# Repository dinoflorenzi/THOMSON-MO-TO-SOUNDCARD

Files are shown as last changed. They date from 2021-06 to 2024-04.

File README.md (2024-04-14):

# PC128 OLIVETTI PRODEST - THOMSON MO/TO SOUNDCARD

# Attention, YM2413 sound card project is still in the prototype state.
# Only the previous versions made have been tested only on PC 128 OLIVETTI PRODEST.
# The last versions with minimal changes and corrections are under test.
# Otherwise, there is an all-in-one version, developed and built by Sebastien that fully works (https://github.com/Sebastus1976/Amadeus).

## PROJECT OVERVIEW
This is a project is born to build a secondary sound card expansion for my PC 128 OLIVETTI PRODEST HOME COMPUTER.<br/>
I have designed and built two different sound cards based on two different sound chip.<br/>
One sound card is based on PSG SN76489AN sound chip, the second is based on OPLL YM2413 sound chip.<br/>
Also i have coded the ASM 6809 routines to play sound demos.<br/>

## HOW IT STARTED
Thomson computers have sound generator simply based on 6bit dac that fully commits the cpu countinuosly updating the sound samples. During sound streaming the computer can't do anything else.<br/>
Beucause of that there was the need to develop a secondary sound card based on specific sound chip that generates sound by itself, only programming your own registers.<br/>
## START POINT
Thomson computers have an expansion port with the main computer signals, data bus, address bus, chip select, master clock, and analog sound input that is mixed with the main sound generator.<br/>
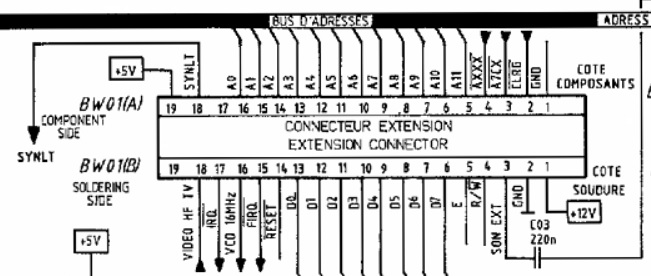
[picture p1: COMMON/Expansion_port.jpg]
<br/>
## SOUND CHIP SELECTION CRITERION
The SN76489AN first chip selection is based on its simple architecture, 8 bit bus, four channels, up to two write sequences to generates sound or noise.<br/>
The YM2413 second chip selection is also based on its simple architecture, 8 bit bus, nine channels, two write addresses to generates sound with hardware instruments and rythems.<br/>
Single board develepments are better described to the links below or wiki section<br/>
[SN76489AN SOUND CARD DEVELOPMENT](https://github.com/dinoflorenzi/THOMSON-MO-TO-SOUNDCARD/wiki/SN76489AN-MOTO-SOUND-CARD)<br/>
[YM2413 SOUND CARD DEVELOPMENT](https://github.com/dinoflorenzi/THOMSON-MO-TO-SOUNDCARD/wiki/YM2413-MOTO-SOUND-CARD)<br/>
## CONTEMPORARY USAGE
By properly setting card jumpers it changes the address. In this way you can mount two sound cards working  simultaneously.<br/>
The interconnection card is a third-party project.<br/>
The assembly of the cards in this photo is the precious contribution of Benoit Rousseau. He help me to debug the cards on Thomson TO target.<br/>
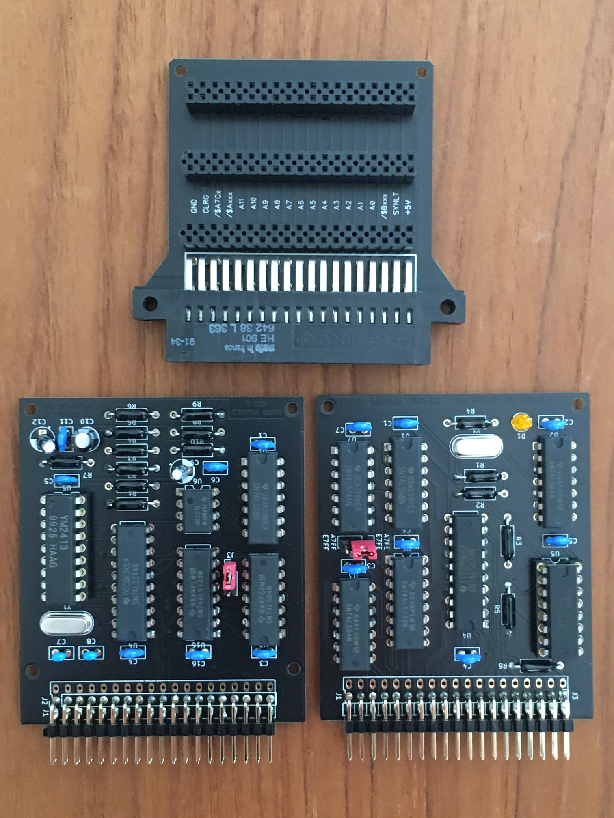
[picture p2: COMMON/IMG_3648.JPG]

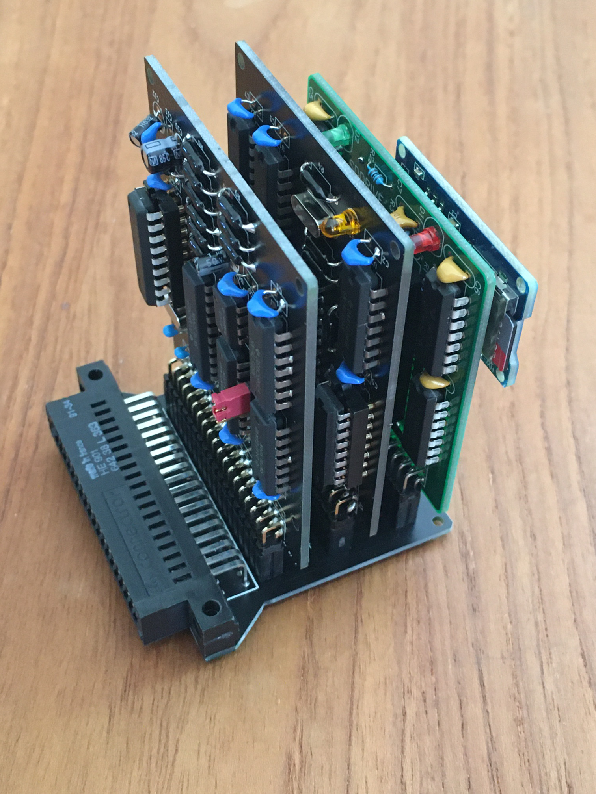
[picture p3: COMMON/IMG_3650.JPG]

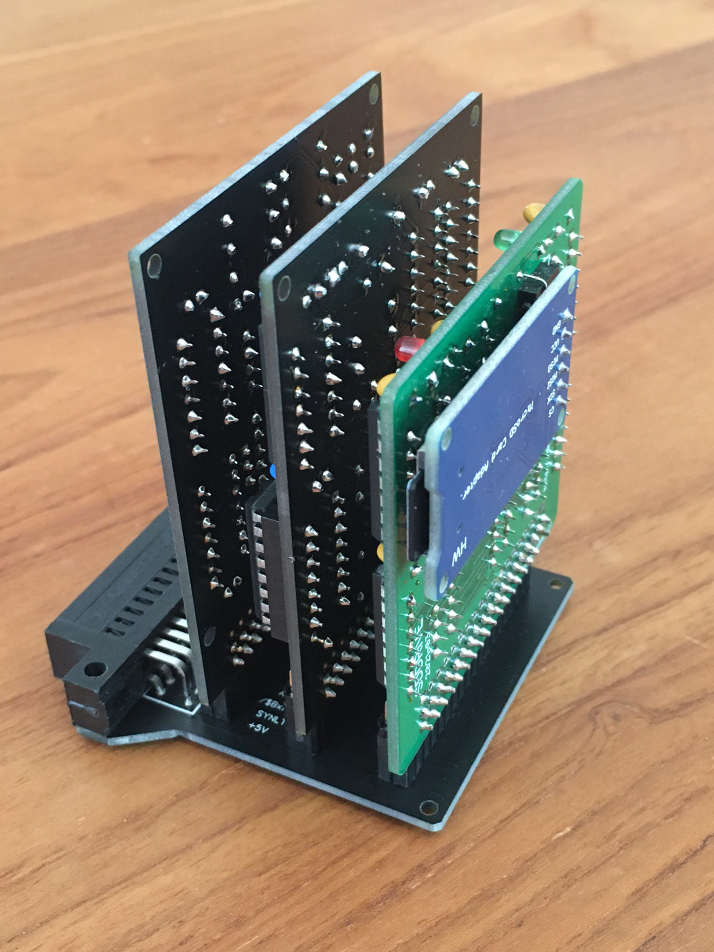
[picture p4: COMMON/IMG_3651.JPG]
<br/>
## SOFTWARE TOOLS
[Kicad](https://www.kicad.org/) and [Freerounting](https://freerouting.org/) to develop schematics and pcb.<br/>
DCMOTO emulator fully emulates both sound cards (http://dcmoto.free.fr/emulateur/index.html)<br/>
## RESOURCES
https://en.wikipedia.org/wiki/Texas_Instruments_SN76489<br/>
https://en.wikipedia.org/wiki/Yamaha_YM2413<br/>
http://dcmoto.free.fr/<br/>
https://vgmrips.net/packs/<br/>
https://www.smspower.org/Music/VGMs<br/>
http://atjs.mbnet.fi/mc6809/<br/>
http://map.grauw.nl/resources/sound/texas_instruments_sn76489an.pdf<br/>
http://map.grauw.nl/resources/sound/yamaha_ym2413_ds.pdf<br/>

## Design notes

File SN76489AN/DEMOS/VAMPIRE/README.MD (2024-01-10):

This folder contains the DCMOTO snapshot of a modified version of the Vampire game for PC 128 Olivetti Prodest(Thomson Mo6). This version uses the SN76489 soundcard or Amadeus soundcard to play a background music.
The files inject.asm and vampire_music.asm contain a detailed description of the assembly code and the steps to modify the original game code. 
https://youtu.be/lTLiAmxgv30

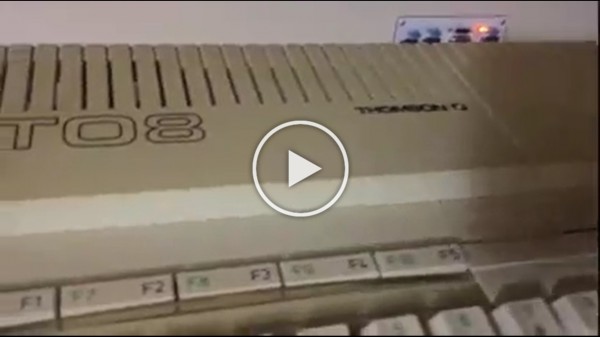
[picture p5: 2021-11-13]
SN76489AN/61901a118f727-fbutube-adnz.jpeg

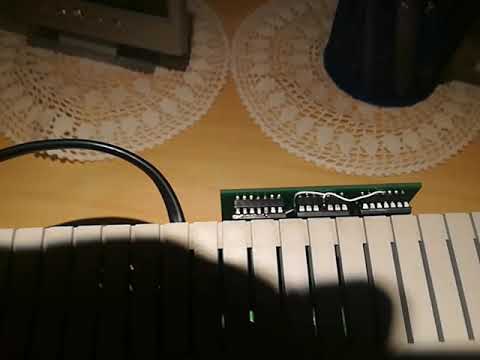
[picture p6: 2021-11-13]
SN76489AN/68747470733a2f2f696d672e796f75747562652e636f6d2f76692f6a7777616a724e703954732f302e6a7067.jpg

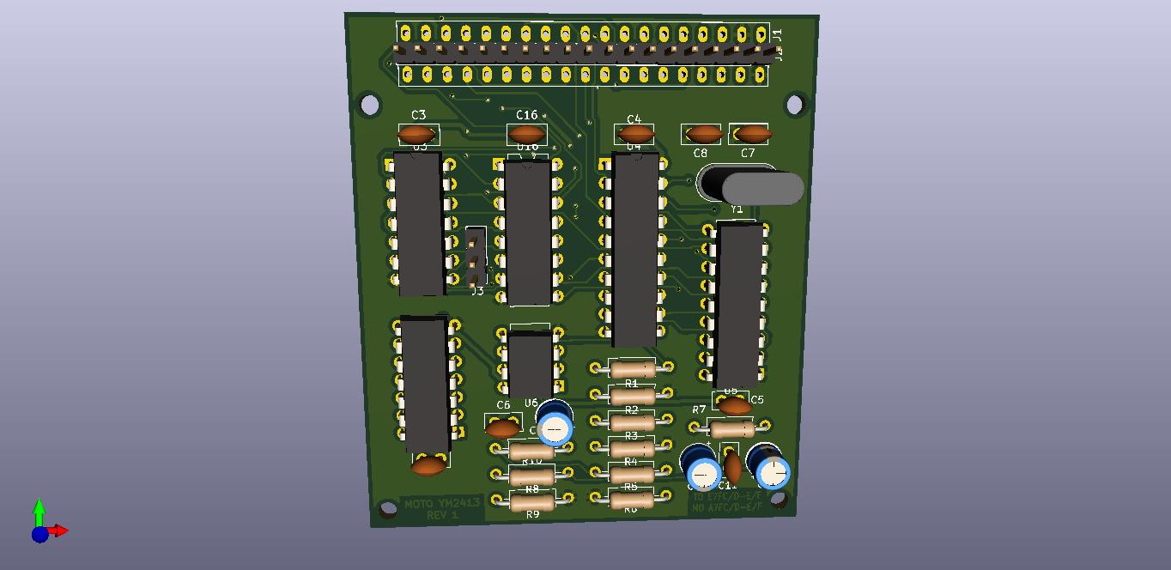
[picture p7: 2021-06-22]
YM2413/YM2413_MOTO_3D.jpg

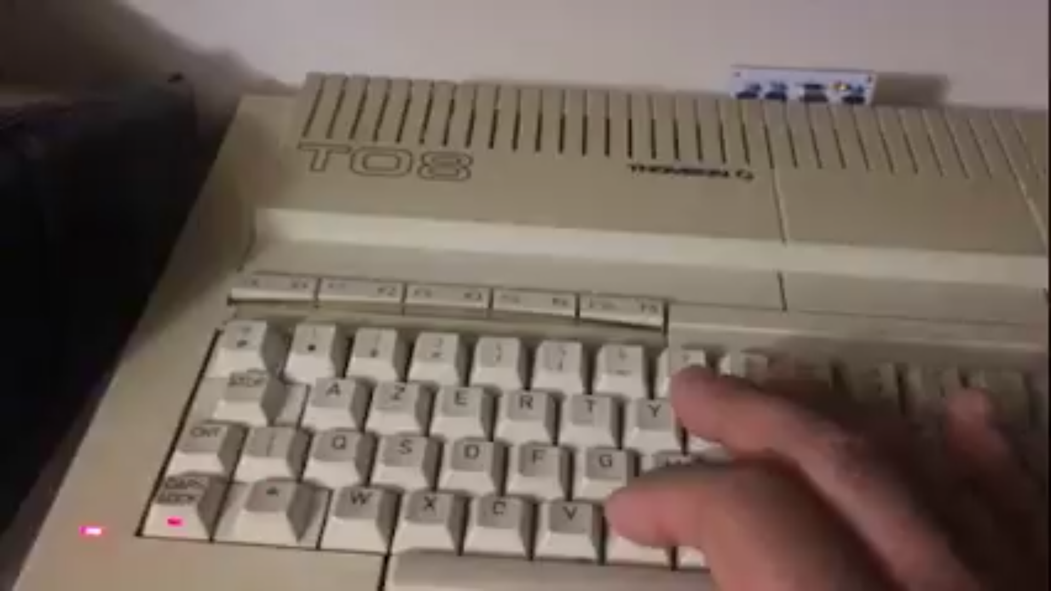
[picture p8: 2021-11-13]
SN76489AN/Screenshot_20211113-132706.png

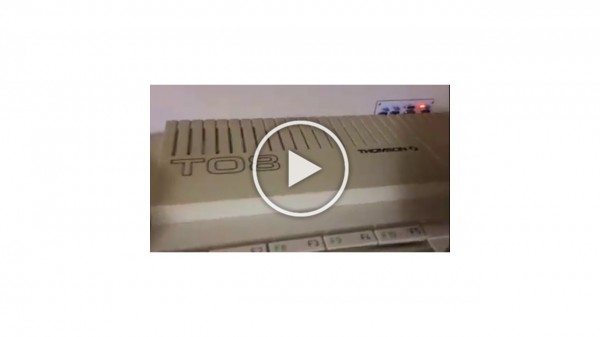
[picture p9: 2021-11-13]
SN76489AN/adnz.jpeg

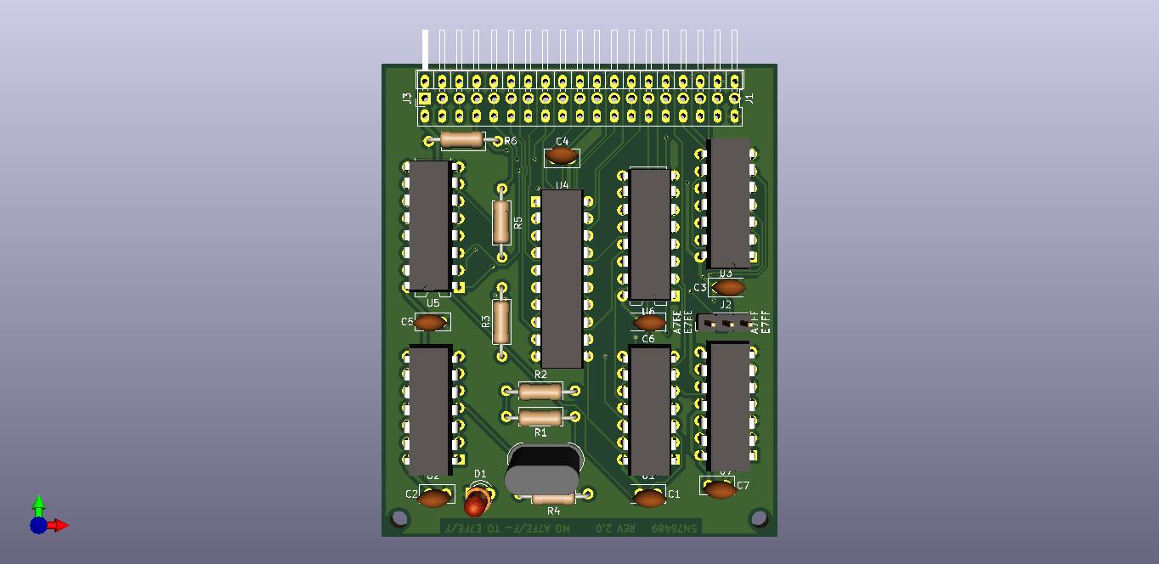
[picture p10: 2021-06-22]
SN76489AN/SN76489_MOTO_3D.jpg

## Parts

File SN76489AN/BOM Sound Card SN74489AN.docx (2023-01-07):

BOM SN76489AN

IC:

-1X 74LS08

-1X 74LS373

-1x 74LS133

-2X 74LS04

-1X SN76489AN

CAPACITORS :

-7X 100nf ceramic

RESISTORS :

-3x 2 kohms metal metal

-1x 250 ohms metal film

-2x 1 kohms film métal

OTHER :

-1X Led 3.5 mm

-1X Quartz 3.579545 Mhz

-1X PCB

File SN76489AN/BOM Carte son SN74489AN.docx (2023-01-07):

BOM SN76489AN

CI:

-1X 74LS08

-1X 74LS373

-1x 74LS133

-2X 74LS04

-1X SN76489AN

CONDENSATEUR :

-7X 100nf céramique multicouches

RESISTANCES :

-3x 2 kohms film métal

-1x 250 ohms film métal

-2x 1 kohms film métal

AUTRES :

-1X Led 3.5 mm

-1X Quartz 3.579545 Mhz

-1X Circuit imprimé

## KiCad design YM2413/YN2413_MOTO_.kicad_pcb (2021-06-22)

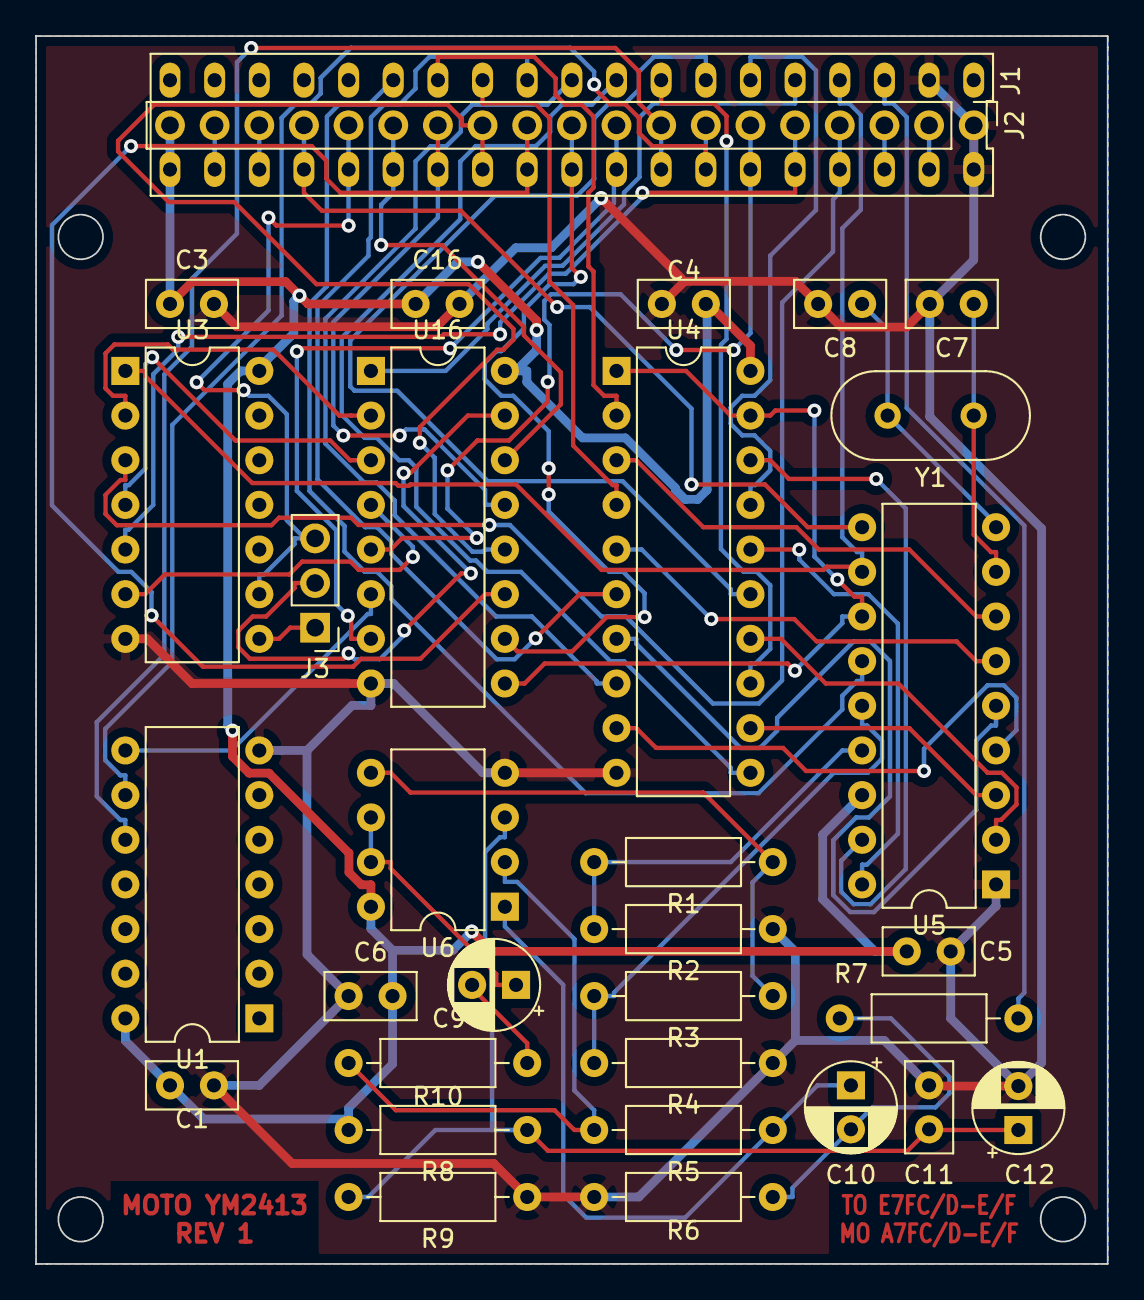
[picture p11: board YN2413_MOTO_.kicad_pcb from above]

Board: 2 copper layers, 61.0 x 69.8 mm, 32 parts (0 on the bottom side), 57 nets.

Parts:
C1, C3, C4, C5, C6, C11, C16: 100nF; C_Disc_D5.0mm_W2.5mm_P2.50mm
C7, C8: 27pF; C_Disc_D5.0mm_W2.5mm_P2.50mm
C9, C12: 1uF; CP_Radial_D5.0mm_P2.50mm
C10: 10uF; CP_Radial_D5.0mm_P2.50mm
J1: Conn_02x19_Row_Letter_Last; DIP-38_Edge_Connector
J2: Conn_01x19; PinHeader_1x19_P2.54mm_Vertical
J3: Conn_01x03_Male; PinHeader_1x03_P2.54mm_Vertical
R1, R3: 4700; R_Axial_DIN0207_L6.3mm_D2.5mm_P10.16mm_Horizontal
R2, R4: 2200; R_Axial_DIN0207_L6.3mm_D2.5mm_P10.16mm_Horizontal
R5: 100K; R_Axial_DIN0207_L6.3mm_D2.5mm_P10.16mm_Horizontal
R6, R7, R8, R9: 1000; R_Axial_DIN0207_L6.3mm_D2.5mm_P10.16mm_Horizontal
R10: 10K; R_Axial_DIN0207_L6.3mm_D2.5mm_P10.16mm_Horizontal
U1: 74LS08; DIP-14_W7.62mm
U3: 74LS04; DIP-14_W7.62mm
U4: 74LS244; DIP-20_W7.62mm
U5: YM2413; DIP-18_W7.62mm
U6: TL072; DIP-8_W7.62mm
U16: 74LS133; DIP-16_W7.62mm
Y1: 3.576 MHz; Crystal_HC18-U_Vertical

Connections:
+5V: C1.1, C3.1, C4.1, C5.1, C6.2, C16.1, J1.19a, J2.19, R8.2, U1.14, U3.14, U4.20, U5.16, U6.8, U16.16
/A1: J1.15a, J2.15, J3.3, U3.9
/A2: J1.14a, J2.14, U16.14
/A3: J1.13a, J2.13, U16.13
/A4: J1.12a, J2.12, U16.12
/A5: J1.11a, J2.11, U16.11
/A6: J1.10a, J2.10, U16.10
/A7: J1.9a, J2.9, U16.7
/A8: J1.8a, J2.8, U1.10
/A9: J1.7a, J2.7, U1.9
/A10: J1.6a, J2.6, U16.5
/A11: J1.5a, J2.5, U3.5
/D0: J1.13b, U4.2
/D1: J1.12b, U4.4
/D2: J1.11b, U4.6
/D3: J1.10b, U4.8
/D4: J1.9b, U4.11
/D5: J1.8b, U4.13
/D6: J1.7b, U4.15
/D7: J1.6b, U4.17
/E: J1.5b, U16.1
/SON: J1.3b, R7.2
/\A7XX: J1.3a, J2.3
/\AXXX: J1.4a, J2.4, U3.3
/\CLRG: J1.2a, J2.2
A0: J1.16a, J2.16, U5.10
GND: C1.2, C3.2, C4.2, C5.2, C6.1, C7.2, C8.2, C11.1, C12.2, C16.2, J1.1a, J1.2b, J2.1, R2.1, R4.1, R6.1, R9.1, U1.7, U3.7, U4.10, U5.1, U6.4, U16.8
unnamed: C7.1, U5.8, Y1.1
unnamed: C8.1, U5.9, Y1.2
unnamed: C9.1, U6.6, U6.7
unnamed: C9.2, R10.2
unnamed: C10.1, R5.1, U6.1
unnamed: C10.2, R6.2, R7.1
unnamed: C11.2, C12.1, R8.1, R9.2, U6.3
unnamed: J1.17a, J2.17
unnamed: J1.18a, J2.18
unnamed: J3.1, U3.8
unnamed: J3.2, U16.15
unnamed: R1.1, R3.1, U6.5
unnamed: R1.2, R2.2, U5.15
unnamed: R3.2, R4.2, U5.14
unnamed: R5.2, R10.1, U6.2
unnamed: U1.8, U16.6
unnamed: U4.3, U5.7
unnamed: U4.5, U5.6
unnamed: U4.7, U5.5
unnamed: U4.9, U5.4
unnamed: U4.12, U5.3
unnamed: U4.14, U5.2
unnamed: U4.16, U5.18
unnamed: U4.18, U5.17
unnamed: U3.2, U16.2
unnamed: U3.4, U16.3
unnamed: U3.6, U16.4
unnamed: U4.1, U4.19, U5.12, U16.9
RESET: J1.14b, U5.13
RW: J1.4b, U3.1, U5.11

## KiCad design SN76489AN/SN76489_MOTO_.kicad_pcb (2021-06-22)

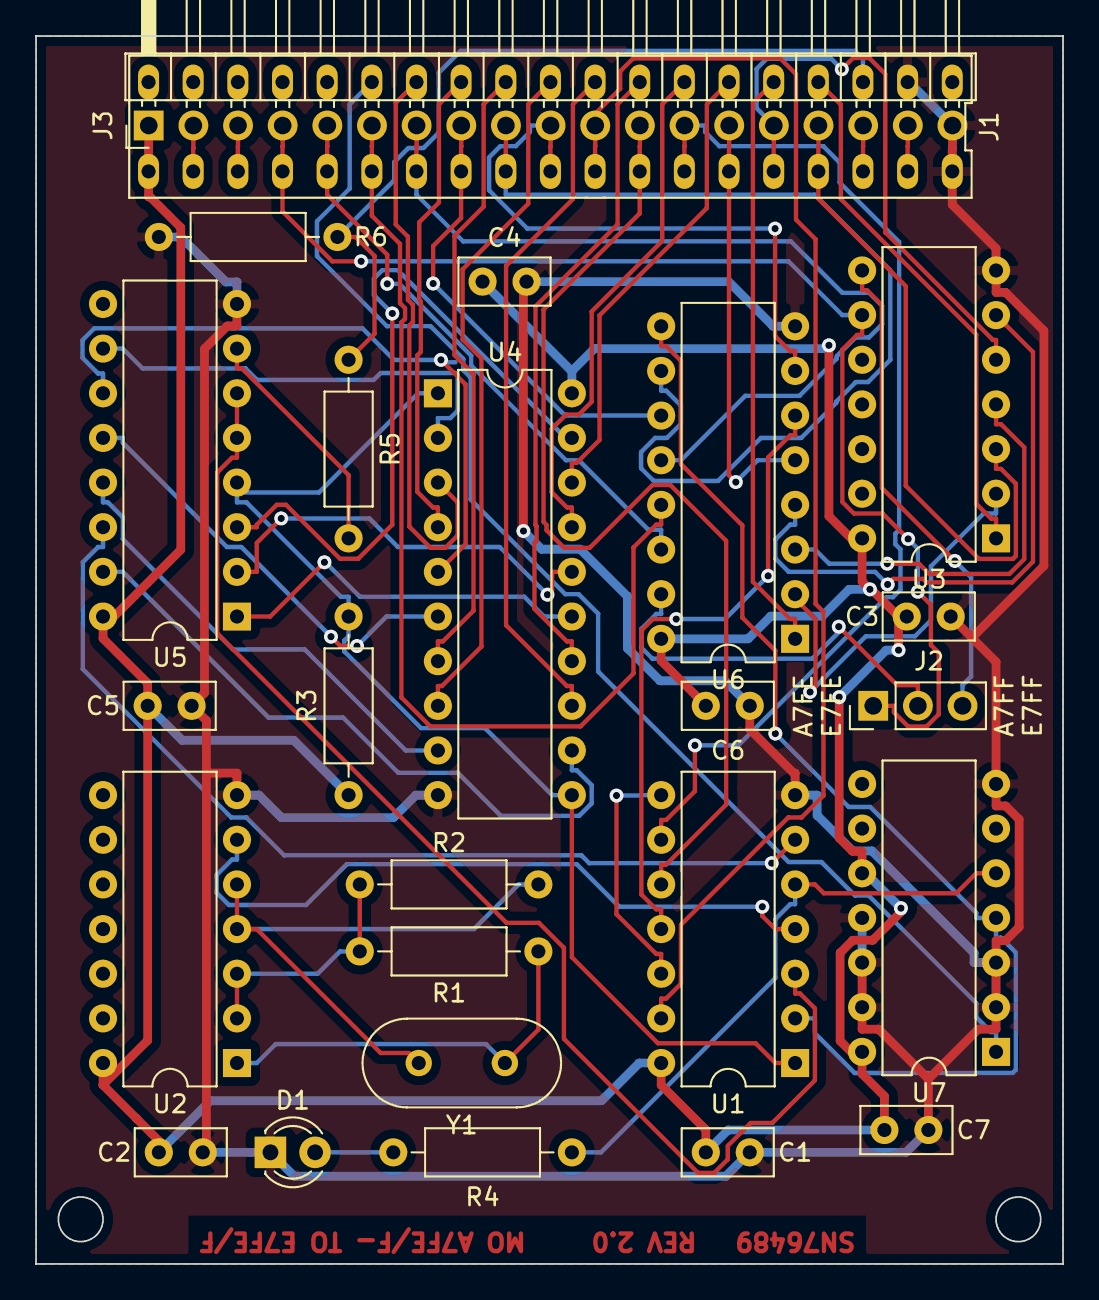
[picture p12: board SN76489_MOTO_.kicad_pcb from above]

Board: 2 copper layers, 58.4 x 69.8 mm, 25 parts (0 on the bottom side), 57 nets.

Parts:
C1, C2, C3, C4, C5, C6, C7: 100nF; C_Disc_D5.0mm_W2.5mm_P2.50mm
D1: LED; LED_D3.0mm
J1: Conn_02x19_Row_Letter_Last; DIP-38_Edge_Connector
J2: Conn_01x03_Male; PinHeader_1x03_P2.54mm_Vertical
J3: Conn_01x19; PinHeader_1x19_P2.54mm_Horizontal
R1, R2, R3: 2000; R_Axial_DIN0207_L6.3mm_D2.5mm_P10.16mm_Horizontal
R4: 250; R_Axial_DIN0207_L6.3mm_D2.5mm_P10.16mm_Horizontal
R5, R6: 1000; R_Axial_DIN0207_L6.3mm_D2.5mm_P10.16mm_Horizontal
U1: 74LS08; DIP-14_W7.62mm
U2, U3: 74LS04; DIP-14_W7.62mm
U4: 74LS373; DIP-20_W7.62mm
U5: SN76489AN; DIP-16_W7.62mm
U6: 74LS133; DIP-16_W7.62mm
U7: 74LS74; DIP-14_W7.62mm
Y1: 3.576 MHz; Crystal_HC18-U_Vertical

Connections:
+5V: C1.1, C2.1, C3.1, C4.1, C5.1, C6.1, C7.1, J1.19a, J3.1, R3.1, U1.14, U2.14, U3.14, U4.20, U5.16, U6.16, U7.10, U7.14
/A0: J1.16a, J2.1, J3.4, U3.9
/A1: J1.15a, J3.5, U6.14
/A2: J1.14a, J3.6, U6.13
/A3: J1.13a, J3.7, U6.12
/A4: J1.12a, J3.8, U6.11
/A5: J1.11a, J3.9, U6.10
/A6: J1.10a, J3.10, U6.7
/A7: J1.9a, J3.11, U1.13
/A8: J1.8a, J3.12, U1.10
/A9: J1.7a, J3.13, U1.9
/A10: J1.6a, J3.14, U6.5
/A11: J1.5a, J3.15, U3.5
/D0: J1.13b, U4.3
/D1: J1.12b, U4.4
/D2: J1.11b, U4.7
/D3: J1.10b, U4.8
/D4: J1.9b, U4.13
/D5: J1.8b, U4.14
/D6: J1.7b, U4.17
/D7: J1.6b, U4.18
/E: J1.5b, U6.1
/LT1: R3.2, U1.1, U4.1, U4.11, U5.4
/RW: J1.4b, U3.1
/SON: J1.3b, R5.1, R6.1
/\EXXX: J1.4a, J3.16, U3.3
/\RESET: J1.14b, U7.1
GND: C1.2, C2.2, C3.2, C4.2, C5.2, C6.2, C7.2, D1.1, J1.1a, J1.2b, J3.19, R6.2, U1.7, U2.7, U3.7, U4.10, U5.8, U6.8, U7.2, U7.3, U7.7, U7.11, U7.12, U7.13
unnamed: D1.2, R4.1
unnamed: J1.2a, J3.18
unnamed: J1.3a, J3.17
unnamed: J1.17a, J3.3
unnamed: J1.18a, J3.2
unnamed: J2.2, U6.15
unnamed: J2.3, U3.8
unnamed: R1.1, U2.1, Y1.1
unnamed: R1.2, R2.1, U2.2, U2.3
unnamed: R2.2, U2.4, U2.5, Y1.2
unnamed: R4.2, U1.5, U7.5
unnamed: R5.2, U5.7
unnamed: U1.2, U6.9, U7.4
unnamed: U1.3, U5.5, U5.6
unnamed: U1.4, U2.6
unnamed: U1.6, U5.14
unnamed: U1.11, U6.6
unnamed: U1.8, U1.12
unnamed: U3.2, U6.2
unnamed: U3.4, U6.3
unnamed: U3.6, U6.4
unnamed: U4.2, U5.10
unnamed: U4.5, U5.11
unnamed: U4.6, U5.12
unnamed: U4.9, U5.13
unnamed: U4.12, U5.15
unnamed: U4.15, U5.1
unnamed: U4.16, U5.2
unnamed: U4.19, U5.3

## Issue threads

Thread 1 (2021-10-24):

YM2413 card noise output

dinoflorenzi, 2021-10-24:
600 Hz noise on output pin 1 of TL072 opa.

dinoflorenzi, 2023-02-28:
The issue has closed by Sebastien
See his github repository
https://github.com/Sebastus1976/Thomson-Soundcard-YM2413

dinoflorenzi, 2023-02-28:
the issue has closed by Sebastien
see his github repository
https://github.com/Sebastus1976/Thomson-Soundcard-YM2413

Closed 2023-02-28.

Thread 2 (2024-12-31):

demo url is broken

adn-z, 2024-12-31:
[SN76489AN SOUND CARD DEVELOPMENT](https://github.com/dinoflorenzi/THOMSON-MO-TO-SOUNDCARD/wiki/SN76489AN-MOTO-SOUND-CARD)

Sound track realized by ADNZ demo url is broken, use this url
(https://oxustudio.com/to8/forum/audios/SN76489-TO8.mp4)

:)

dinoflorenzi, 2024-12-31:
Link updated.
Thank you very much ADNZ🙂

dinoflorenzi, 2024-12-31:
Closed

dinoflorenzi, 2024-12-31:
Closed

Closed 2024-12-31.
